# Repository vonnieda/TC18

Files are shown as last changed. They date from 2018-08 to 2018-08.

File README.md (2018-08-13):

# TC18

An IV-18 VFD tube clock by Jason von Nieda <jason@vonnieda.org>

This work is licensed under a Creative Commons Attribution-Share Alike 3.0 
United States License.
See http://creativecommons.org/licenses/by-sa/3.0/us/ for more information.

The enclosure of this clock was designed by John Pfeiffer at 
http://blog.giantpachinkomachineofdoom.com/

Parts of the circuit are based on Ladyada's Ice Tube clock at 
http://www.ladyada.net/make/icetube/
That clock is sold in kit form by Adafruit at 
http://www.adafruit.com/index.php?main_page=product_info&cPath=39&products_id=194

Some of the parts used in the schematic and board drawings are from 
the Sparkfun Eagle library at 
http://www.opencircuits.com/SFE_Footprint_Library_Eagle

# Manifest
* TC18-v3.brd: Eagle Board file.
* TC18-v3.sch: Eagle Schematic file.
* TC18.pde: Arduino sketch - this is the entire source code.
* TC18.xls: Spreadsheet containing notes, BOM and ordering info. OpenOffice and Google Docs compatible.
* FRAME 1V2.DXF: The first metal frame - rectangle with D shape cut from center.
* FRAME 2V2.DXF: The second metal frame - rectangle with rectangle cut from center.
* FRAME 3V2.DXF: The third metal frame - X shape with rectangle cut from center.
* FRAME 4V2.DXF: The fourth metal frame - this has not yet been made or proofed. Four of these will be made to go inside the perforated metal as fillers. These will be black.
* FRAME V2.DXF: Template for the metal frames. Used as the starting point for all of the above.
* PERFFORM.DXF: Used to make the wooden form that I bend the perforated aluminum around. The form is made from 2 identical pieces of 3/4" MDF glued up to be 1.5".
	
# Build Notes
I have put up a web page about this clock. If something appears to be missing from here, try checking there first:
http://www.vonnieda.org/tc18
    
# Enclosure Parts List
* 8 2.5" long 1/4" 28NF hex socket cap bolts, black oxide
* 2 "FRAME 1V2"
* 2 "FRAME 2V2"
* 2 "FRAME 3V2"
* 24 Buna-N O-Ring AS568A Dash Number 108 http://www.mcmaster.com/nav/enter.asp?partnum=9452K171&pagenum=3423
* 8 .25" length polished 6061 aluminum tube 0.375" OD x 0.065" wall x 0.245" ID bored out to .25" ID
* 8 3" length polished 6061 aluminum tube 0.375" OD x 0.065" wall x 0.245" ID with ends tapped for the bolts and to about 1" deep
* 2 end sleeves - 3003-H14 perforated aluminum 0.063" thick (0.0625" dia. holes) 0.125" stagger. Approx 1" wide formed around "PERFFORM.DXF", joined at bottom and painted gloss black

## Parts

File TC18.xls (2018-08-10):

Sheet: BOM V3
Quantity | Part | Package | Supplier | Part Number | Number in Stock | Min Quantity | Price | Extended | Notes
1 | MCU AVR 32K FLASH 32TQFP |  | Digikey | ATMEGA328P-AU-ND | 10 | 1 | $4.30
1 | IC RTC W/TCXO 16-SOIC |  | Digikey | DS3231S#-ND | 2 | 1 | $7.42
1 | MC33269D-3.3 IC REG LDO 800MA 3.3V DPAK |  | Digikey | MC33269DT-3.3GOS-ND | 1 | 1 | $0.85
1 | INDUCTOR 220UH .57A SMD SHIELDED | 0.287" L x 0.287" W x 0.180" H (7.30mm x 7.30mm x 4.55mm) | Digikey | 811-1174-1-ND | 1 | 1 | $0.96
1 | DIODE SCHOTTKY 1A 80V DO-214AA | DO-214AA, SMB | Digikey | 641-1108-1-ND | 1 | 1 | $0.42
1 | MOSFET N-CH 100V 4.3A DPAK | DPak, TO-252 (2 leads+tab), SC-63 | Digikey | IRLR110PBFCT-ND | 1 | 1 | $1.85
1 | CAP CER .10UF 100V X7R 0805 | 0805 | Digikey | HMK212B7104KG-T | 8 | 10 | $0.19
1 | CAP 22UF 63V ELECT HA SMD | 0.315" Dia x 0.244" H (8.00mm x 6.20mm) | Digikey | PCE4230CT-ND | 10 | 5 | $0.44
2 | CAP 47UF 25V ELECT HA SMD | 0.248" Dia x 0.213" H (6.30mm x 5.40mm) | Digikey | PCE3297CT-ND | 10 | 5 | $0.29
1 | CONN POWER JACK 2.1X5.5MM HI CUR |  | Digikey | CP-002AHPJCT-ND | 1 | 1 | $0.90
1 | CRYSTAL 16.00 MHZ 8.0 PF SMD |  | Digikey | 644-1135-1-ND | 0 | 1 | $1.70
2 | CAP CERAMIC 8.0PF 50V NP0 0805 | 0805 | Digikey | 311-1097-1-ND | 50 | 10 | $0.06
1 | HOLDER BATTERY COIN 12MM DIA SMD |  | Digikey | 3000K-ND | 2 | 1 | $0.57
1 | KNOB BLK GLOSS .50"DIA 6MM SHAFT |  | Digikey | 226-1152-ND | 3 | 1 | $3.80
1 | ENCODER ROTARY 11MM HORIZ 20PPR |  | Digikey | 102-1754-ND | 1 | 1 | $3.60
1 | PTC RESET 30V .200A SMD 1210 |  | Digikey | F3350CT-ND | 10 | 1 | $0.54
1 | CR1225 12mm 47mAh coin cell batteries. |  | SparkFun | PRT-00337 | 2 | 1 | $1.95
1 | Wall Adapter Power Supply - 5VDC 1A |  | SparkFun | TOL-08269 | 3 | 1 | $5.95
1 | MAX6921 |  | Maxim | MAX6921AWI+ | 1 | 1 | $9.09
1 | IV-18 Tube |  | eBay | IV-18 | 13 | 5 | $5.20
1 | TC18v3 PCB |  | Gold Phoenix | TC18v3 | 40 | 22 | $4.23

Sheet: V2 Board Errata
Lots of solder mask areas too large leaving traces uncovered. Around battery connector and mosfets. | Fixed in V3 and GoldPhoenix.dru
Forgot to wire MISO | Fixed in V3
Need more offset on the locking pins, they didn't do much. Maybe equal amount on opposite pins. | Fixed in V3 and JVN.lib
Electrolytic pads could be a little further out from center. Not critical. | Won't Fix
Change ext to be a standard Arduino header with DTR reset | Fixed in V3
Mosfet gate needs to be pulled down, currently floating if chip is not running properly | Fixed in V3
DS3231 silk not showing pin 1 | Fixed in V3
Maybe add a limiting resistor for mosfet path | Fixed in V3 with PTC
Maybe add a fuse for the whole thing (PTC) | Fixed in V3
Looks like I need to use the longer encoder | Fixed in V3
Board needs to be about 30 thous smaller in each dimension | Won't Fix
Need room for spacer around bolts | Fixed in V3
Change to smaller caps for the 25v/47uF | Fixed in V3

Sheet: Next Order
1 | 10 | MC33269DT-3.3GOS-ND | IC REG LDO 800MA 3.3V DPAK | 0 | 0.85 | 8.5
2 | 10 | 811-1174-1-ND | INDUCTOR 220UH .57A SMD SHIELDED | 0 | 0.84 | 8.4
3 | 10 | 641-1108-1-ND | DIODE SCHOTTKY 1A 80V DO-214AA | 0 | 0.318 | 3.18
4 | 4 | IRLR110PBFCT-ND | MOSFET N-CH 100V 4.3A DPAK | 0 | 1.85 | 7.4
5 | 4 | CP-002AHPJCT-ND | CONN POWER JACK 2.1X5.5MM HI CUR | 0 | 0.9 | 3.6
6 | 10 | 644-1135-1-ND | CRYSTAL 16.00 MHZ 8.0 PF SMD | 0 | 1.474 | 14.74
7 | 10 | 3000K-ND | HOLDER BATTERY COIN 12MM DIA SMD | 0 | 0.495 | 4.95
8 | 4 | 102-1754-ND | ENCODER ROTARY 11MM HORIZ 20PPR | 0 | 3.6 | 14.4

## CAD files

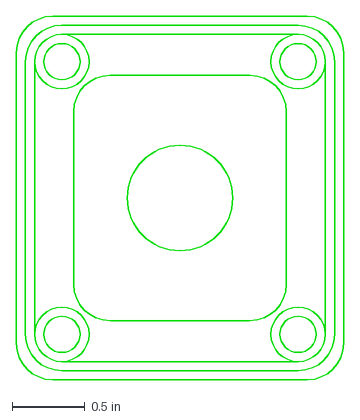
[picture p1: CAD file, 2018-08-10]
CAD/FRAME V2.DXF
2.25 x 2.50 in

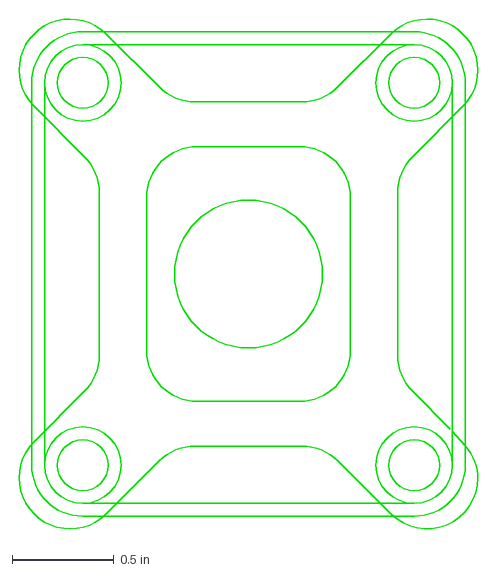
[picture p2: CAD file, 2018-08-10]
CAD/FRAME 3V2.DXF
2.28 x 2.53 in

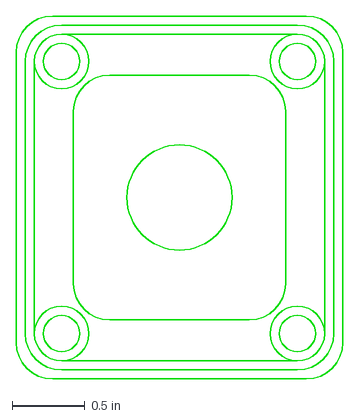
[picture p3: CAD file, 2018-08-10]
CAD/FRAME 4V2.DXF
2.25 x 2.50 in

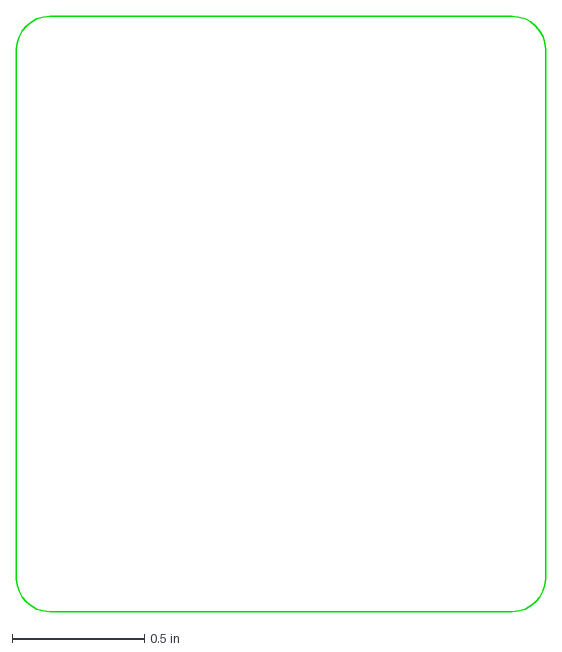
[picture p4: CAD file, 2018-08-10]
CAD/PERF FORM.DXF
2.00 x 2.25 in

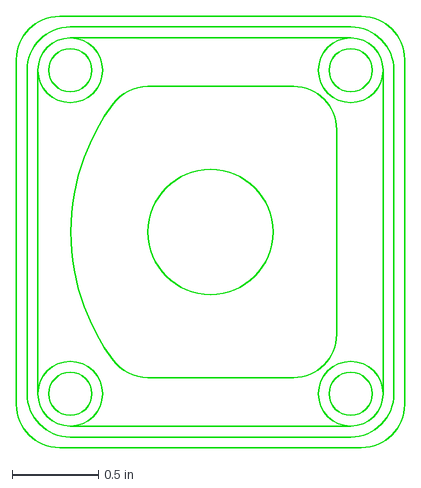
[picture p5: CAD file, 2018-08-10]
CAD/FRAME 1V2.DXF
2.25 x 2.50 in

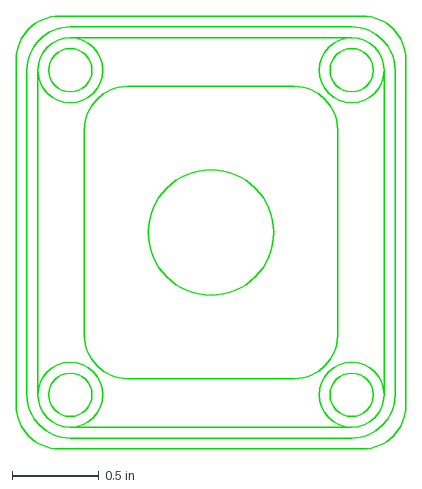
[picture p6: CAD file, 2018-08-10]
CAD/FRAME 2V2.DXF
2.25 x 2.50 in

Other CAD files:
TC18-Case.skp
TC18.skp

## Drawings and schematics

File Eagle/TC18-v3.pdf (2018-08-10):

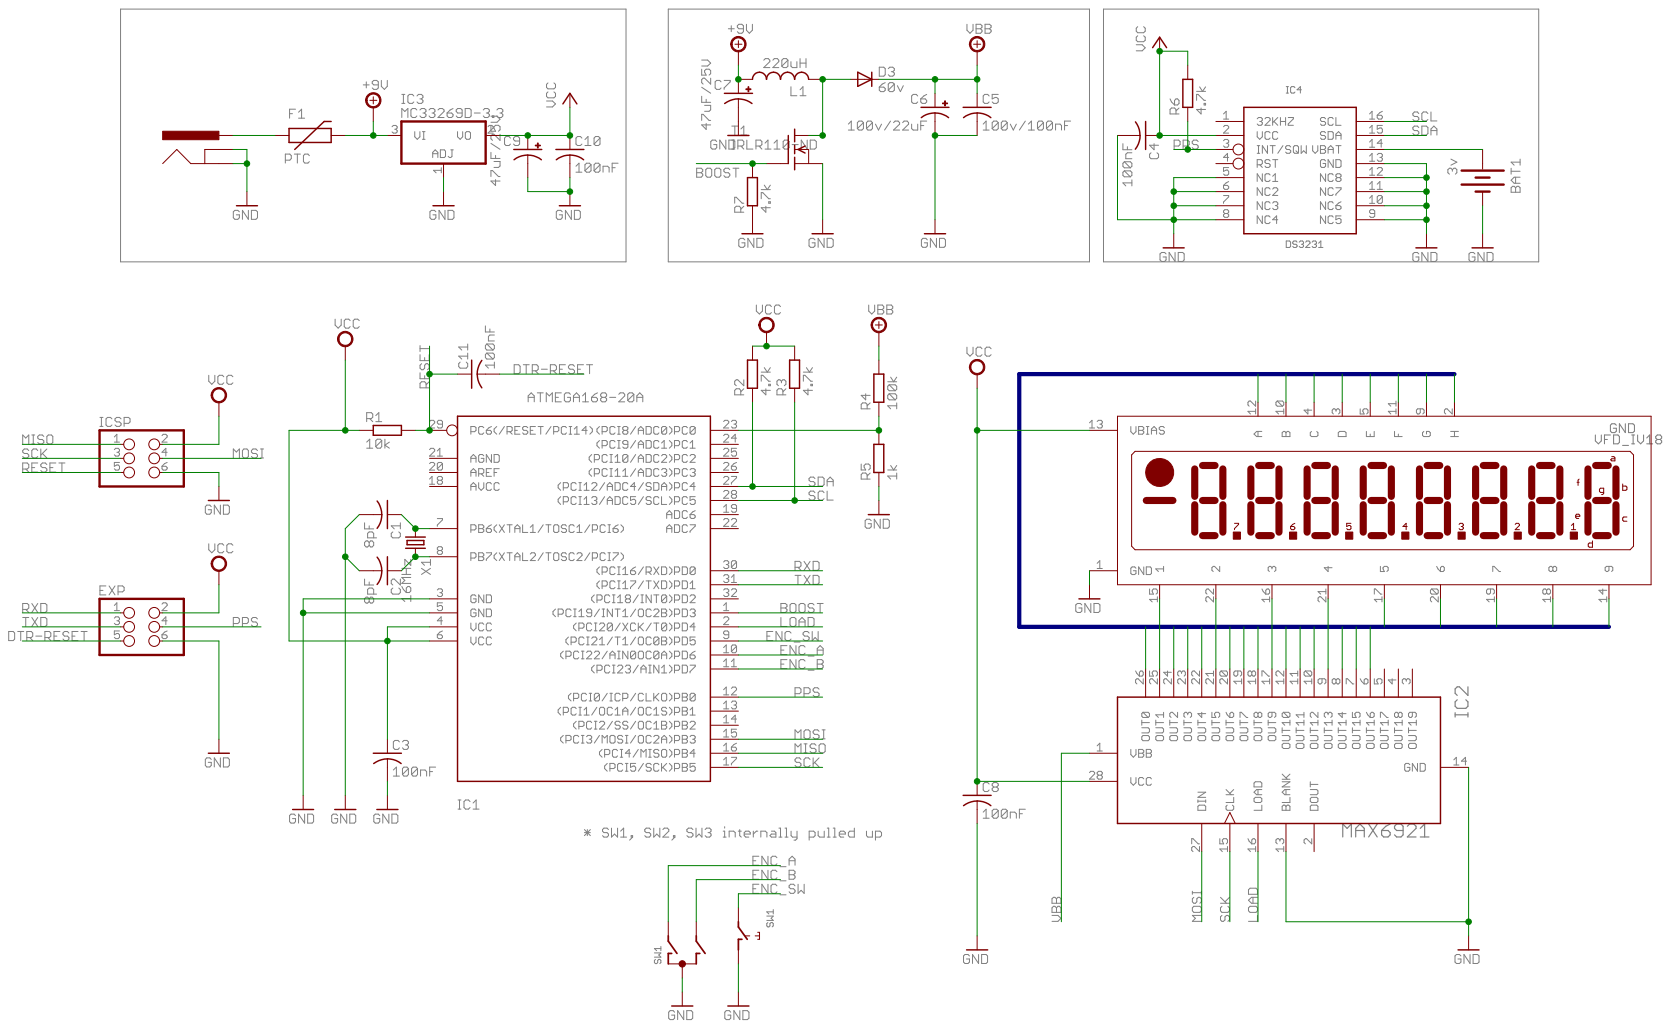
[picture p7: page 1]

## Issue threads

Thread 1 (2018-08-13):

No need to wait after Wire.requestFrom().

Koepel, 2018-08-13:
In the file "TC18/Arduino/TC18/TC18.ino", you may remove all the `while (Wire.available() < ...` after a Wire.requestFrom().
Explanation: [Common-mistakes#1](https://github.com/Koepel/How-to-use-the-Arduino-Wire-library/wiki/Common-mistakes#1)

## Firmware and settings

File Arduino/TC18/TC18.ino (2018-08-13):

/*
* TC18 by Jason von Nieda <jason@vonnieda.org>
* License: CC BY-SA
* 
* Board Configuration
*  Arduino Duemilanove or Diecimila, ATmega328P or ATmega168 @ 16MHz
*  Arduino will set the brown out detect too high on burning the bootloader
*  so it has to be changed to 1.8 manually.
*  VBB feedback       Analog 0 (PC0)
*    VBB with 100k to 1k voltage divider
*  SCK to MAX6921     Digital 13 (PB5)
*  MOSI to MAX6921    Digital 11 (PB3)
*  PPS                Digital 8 (PB0)
*  SW2 (ENC_B)        Digital 7 (PD7)
*  SW1 (ENC_A)        Digital 6 (PD6)
*  SW3 (ENC_SW)       Digital 5 (PD5)
*  LOAD               Digital 4 (PD4)
*  BOOST              Digital 3 (PD3)
*  SDA                Analog 4 (PC4)
*  SCL                Analog 5 (PC5)
*  RXD                Digital 0 (PD0)
*  TXD                Digital 1 (PD1)
*/


// Used only for testing a board after programming
//#define TESTMODE     1

#include <avr/interrupt.h>
#include <stdlib.h>
#include <stdio.h>
#include <Wire.h>
#include <EEPROM.h>

#define DS3231_ADDR   0b01101000

#define VFDLOAD_DDR   DDRD
#define VFDLOAD_PORT  PORTD
#define VFDLOAD       PORTD4

#define BOOST_DDR     DDRD
#define BOOST_PORT    PORTD
#define BOOST         PORTD3

#define PPS_DDR       DDRB
#define PPS_PIN       PINB
#define PPS           PORTB0

#define ENC_A_DDR     DDRD
#define ENC_A_PIN     PIND
#define ENC_A_PORT    PORTD
#define ENC_A         PORTD6

#define ENC_B_DDR     DDRD
#define ENC_B_PIN     PIND
#define ENC_B_PORT    PORTD
#define ENC_B         PORTD7

#define ENC_SW_DDR    DDRD
#define ENC_SW_PIN    PIND
#define ENC_SW_PORT   PORTD
#define ENC_SW        PORTD5

#define VFD_SEG_A     0b00000001
#define VFD_SEG_B     0b00000010
#define VFD_SEG_C     0b00000100
#define VFD_SEG_D     0b00001000
#define VFD_SEG_E     0b00010000
#define VFD_SEG_F     0b00100000
#define VFD_SEG_G     0b01000000
#define VFD_SEG_H     0b10000000

#define VFD_DIGIT_0   0b000000001
#define VFD_DIGIT_1   0b000000010
#define VFD_DIGIT_2   0b000000100
#define VFD_DIGIT_3   0b000001000
#define VFD_DIGIT_4   0b000010000
#define VFD_DIGIT_5   0b000100000
#define VFD_DIGIT_6   0b001000000
#define VFD_DIGIT_7   0b010000000
#define VFD_DIGIT_8   0b100000000

#define MENU_TIMEOUT  10000

static const byte vfd_font[] = {
  /* 0 - 9 */
  VFD_SEG_A | VFD_SEG_B | VFD_SEG_C | VFD_SEG_D | VFD_SEG_E | VFD_SEG_F,
  VFD_SEG_B | VFD_SEG_C,
  VFD_SEG_A | VFD_SEG_B | VFD_SEG_D | VFD_SEG_E | VFD_SEG_G,
  VFD_SEG_A | VFD_SEG_B | VFD_SEG_C | VFD_SEG_D | VFD_SEG_G,
  VFD_SEG_B | VFD_SEG_C | VFD_SEG_F | VFD_SEG_G,
  VFD_SEG_A | VFD_SEG_C | VFD_SEG_D | VFD_SEG_F | VFD_SEG_G,
  VFD_SEG_A | VFD_SEG_C | VFD_SEG_D | VFD_SEG_E | VFD_SEG_F | VFD_SEG_G,
  VFD_SEG_A | VFD_SEG_B | VFD_SEG_C,
  VFD_SEG_A | VFD_SEG_B | VFD_SEG_C | VFD_SEG_D | VFD_SEG_E | VFD_SEG_F | VFD_SEG_G,
  VFD_SEG_A | VFD_SEG_B | VFD_SEG_C | VFD_SEG_F | VFD_SEG_G,
  
  /* a - z */
  VFD_SEG_A | VFD_SEG_B | VFD_SEG_C | VFD_SEG_D | VFD_SEG_E | VFD_SEG_G,
  VFD_SEG_C | VFD_SEG_D | VFD_SEG_E | VFD_SEG_F | VFD_SEG_G,
  VFD_SEG_D | VFD_SEG_E | VFD_SEG_G,
  VFD_SEG_B | VFD_SEG_C | VFD_SEG_D | VFD_SEG_E | VFD_SEG_G,
  VFD_SEG_A | VFD_SEG_B | VFD_SEG_D | VFD_SEG_E | VFD_SEG_F | VFD_SEG_G,
  VFD_SEG_A | VFD_SEG_E | VFD_SEG_F | VFD_SEG_G,
  VFD_SEG_A | VFD_SEG_B | VFD_SEG_C | VFD_SEG_D | VFD_SEG_F | VFD_SEG_G,
  VFD_SEG_C | VFD_SEG_E | VFD_SEG_F | VFD_SEG_G,
  VFD_SEG_B | VFD_SEG_C,
  VFD_SEG_B | VFD_SEG_C | VFD_SEG_D | VFD_SEG_E,
  VFD_SEG_A | VFD_SEG_C | VFD_SEG_E | VFD_SEG_F | VFD_SEG_G,
  VFD_SEG_D | VFD_SEG_E | VFD_SEG_F,
  VFD_SEG_A | VFD_SEG_C | VFD_SEG_E | VFD_SEG_G,
  VFD_SEG_C | VFD_SEG_E | VFD_SEG_G,
  VFD_SEG_C | VFD_SEG_D | VFD_SEG_E | VFD_SEG_G,
  VFD_SEG_A | VFD_SEG_B | VFD_SEG_E | VFD_SEG_F | VFD_SEG_G,
  VFD_SEG_A | VFD_SEG_B | VFD_SEG_C | VFD_SEG_D | VFD_SEG_G | VFD_SEG_H,
  VFD_SEG_E | VFD_SEG_G,
  VFD_SEG_A | VFD_SEG_C | VFD_SEG_D | VFD_SEG_F | VFD_SEG_G,
  VFD_SEG_D | VFD_SEG_E | VFD_SEG_F | VFD_SEG_G,
  VFD_SEG_C | VFD_SEG_D | VFD_SEG_E,
  VFD_SEG_C | VFD_SEG_D | VFD_SEG_E,
  VFD_SEG_A | VFD_SEG_C | VFD_SEG_D | VFD_SEG_E,
  VFD_SEG_B | VFD_SEG_C | VFD_SEG_E | VFD_SEG_F | VFD_SEG_G,
  VFD_SEG_B | VFD_SEG_C | VFD_SEG_D | VFD_SEG_F | VFD_SEG_G,
  VFD_SEG_A | VFD_SEG_B | VFD_SEG_D | VFD_SEG_E | VFD_SEG_G,
};

static const char *month_abbrevs[] = {
  "Jan",
  "Feb",
  "Mar",
  "Apr",
  "May",
  "Jun",
  "Jul",
  "Aug",
  "Sep",
  "Oct",
  "Nov",
  "Dec",
};

volatile byte vfd_data[9];
volatile byte vfd_digit;
// Digit dwell is used to adjust the brightness of individual digits on
// the display. Used to compensate for tube manufacturing differences.
// Increasing the value of a position causes the refresh loop to dwell on
// that digit for additional cycles causing it's brightness to increase.
// Use sparingly. This slows the refresh of the entire display.
// No need to change here, there is a menu option and it is saved
// to EEPROM.
volatile byte vfd_digit_dwell[] = {
  0, 0, 0, 0, 0, 0, 0, 0, 0
};
volatile byte vfd_digit_dwell_count;
volatile unsigned long spi_buffer;
volatile byte spi_buffer_count;

// Default boost voltage used during startup, this is quickly replaced by the
// config data
float voltage_target = 30.00;
// The allowable voltage +/- drift before the ADC interrupt makes adjustements
static const float voltage_drift = 3.00;
// The current voltage as measured by the ADC
float voltage;
// The number of times the voltage has been sampled. This is used to limit
// the frequency of updates to the boost PWM.
byte voltage_sample;

volatile char encoder_debounce = -1;
volatile char encoder_pos;
volatile char encoder_pressed;

volatile byte hour, minute, second, year, month, date;
volatile unsigned int millisecond;
volatile float temperature;

// Used in many main loop functions to format text for display
char display_buf[20];

// Configurable options, pulled from EEPROM at startup and stored
// when changed.
char display_mode;
char brightness;
char bank_mode;
char glitch_mode;

#define GLITCHES 3
static int glitch_digit[GLITCHES];
static int glitch_segment[GLITCHES];
static int glitch_count[GLITCHES];
static bool glitch_on[GLITCHES];

void setup() {
  Serial.begin(19200);
  
  BOOST_DDR |= _BV(BOOST);

  // Timer 2 is used to create the waveform for the boost controller
  // Timer 2 Waveform Generation Mode 3 Fast PWM
  // Compare Output Mode Clear OC2B on Compare Match, set OC2B at BOTTOM
  TCCR2A = _BV(WGM21) | _BV(WGM20) | _BV(COM2B1);
  // Clock Select No Prescaling
  TCCR2B = _BV(CS20);
  // Initial value for boost timer
  OCR2B = 230;
  
  // Timer 1 is used to refresh the VFD display
  // Set defaults in case Arduino screws them up
  TCCR1A = 0;
  // Clock Select No Prescaling
  TCCR1B = _BV(CS10);
  // Interrupt Enable
  TIMSK1 = _BV(TOIE1);
  
  // Internal 1.1V Voltage Reference, Single Ended Input on ADC0
  ADMUX = _BV(REFS1) | _BV(REFS0);
  // ADC Enable, ADC Auto Trigger Enable, ADC Interrupt Enable
  // ADC Prescaler 128
  ADCSRA |= _BV(ADEN) | _BV(ADATE) | _BV(ADIE) 
    | _BV(ADPS2) | _BV(ADPS1) | _BV(ADPS0);
  // ADC Start Conversion (starts free running mode)
  ADCSRA |= _BV(ADSC);
  
  // Enable SS, MOSI and SCK as outputs, required by SPI
  DDRB |= _BV(PORTB2) | _BV(PORTB3) | _BV(PORTB5);
  // SPI Enable, Master Mode, Interrupt Enable, FOSC/16
  SPCR = _BV(SPE) | _BV(MSTR) | _BV(SPR0) | _BV(SPIE);
 
  VFDLOAD_DDR |= _BV(VFDLOAD);
  
  // Enable Pin Change Interrupt 0 PCINT0 (PB0) [PPS]
  PCICR |= _BV(PCIE0);
  PCMSK0 |= _BV(PCINT0);
  
  // Set ENC_A, ENC_B and ENC_SW pins to input
  ENC_A_DDR &= ~(_BV(ENC_A));
  ENC_B_DDR &= ~(_BV(ENC_B));
  ENC_SW_DDR &= ~(_BV(ENC_SW));
  
  // Turn on internal pullups for ENC_A, ENC_B, ENC_SW
  ENC_A_PORT |= _BV(ENC_A);
  ENC_B_PORT |= _BV(ENC_B);
  ENC_SW_PORT |= _BV(ENC_SW);
  
  // Enable Pin Change Interrupt 2 for PCINT22 (PD6) [ENC_A], PCINT23 (PD7) [ENC_B], PCINT21 (PD5) [ENC_SW]
  PCMSK2 |= _BV(PCINT21);
  PCMSK2 |= _BV(PCINT22);
  PCMSK2 |= _BV(PCINT23);
  PCICR |= _BV(PCIE2);
  
  ds3231_setup();
  
  load_config();
}

void ds3231_setup() {
  Wire.begin();
  // set the control register
  ds3231_set_register(0x0e, 0b00000000);
}

byte dec_to_bcd(int dec) {
  return ((dec % 10) | ((dec / 10) << 4));
}

int bcd_to_dec(byte bcd) {
  return (((bcd >> 4) * 10) + (bcd & 0x0f));
}

void ds3231_set_register(byte address, byte value) {
  Wire.beginTransmission(DS3231_ADDR);
  Wire.write(address);
  Wire.write(value);
  Wire.endTransmission();
}

byte ds3231_get_register(byte address) {
  Wire.beginTransmission(DS3231_ADDR);
  Wire.write(address);
  Wire.endTransmission();
  Wire.requestFrom(DS3231_ADDR, 1);
  while (Wire.available() < 1);
  return Wire.read();
}

void ds3231_set_time(byte hour, byte minute, byte second) {
  Wire.beginTransmission(DS3231_ADDR);
  Wire.write(0x00);
  Wire.write(dec_to_bcd(second));
  Wire.write(dec_to_bcd(minute));
  Wire.write(dec_to_bcd(hour));
  Wire.endTransmission();
}

void ds3231_get_time(byte *hour, byte *minute, byte *second) {
  Wire.beginTransmission(DS3231_ADDR);
  Wire.write(0x00);
  Wire.endTransmission();
  Wire.requestFrom(DS3231_ADDR, 3);
  while (Wire.available() < 3);
  byte s = Wire.read();
  byte m = Wire.read();
  byte h = Wire.read();
  *second = bcd_to_dec(s);
  *minute = bcd_to_dec(m);
  *hour = bcd_to_dec(h);
}

void ds3231_set_date(byte year, byte month, byte date) {
  Wire.beginTransmission(DS3231_ADDR);
  Wire.write(0x04);
  Wire.write(dec_to_bcd(date));
  Wire.write(dec_to_bcd(month));
  Wire.write(dec_to_bcd(year));
  Wire.endTransmission();
}

void ds3231_get_date(byte *year, byte *month, byte *date) {
  Wire.beginTransmission(DS3231_ADDR);
  Wire.write(0x04);
  Wire.endTransmission();
  Wire.requestFrom(DS3231_ADDR, 3);
  while (Wire.available() < 3);
  byte d = Wire.read();
  byte m = Wire.read();
  byte y = Wire.read();
  *date = bcd_to_dec(d);
  *month = bcd_to_dec(m & 0b00011111);
  *year = bcd_to_dec(y);
}

float ds3231_get_temp() {
  byte msb = ds3231_get_register(0x11);
  byte lsb = ds3231_get_register(0x12);
  float c = msb + ((lsb >> 6) * 0.25f);
  return c;
}

/*
  Load the given VFD data into the SPI buffer and start the transfer.
  This sends the first byte of the data. The rest is sent from the
  SPI interrupt.
*/
static inline void vfd_send(unsigned long d) {
  spi_buffer = d << 8;
  spi_buffer_count = 3;
  
  SPDR = (spi_buffer >> 24);
  spi_buffer <<= 8;
  spi_buffer_count--;
}

/*
  Refresh the VFD by showing the next digit
*/
static inline void vfd_refresh() {
  if (vfd_digit_dwell_count--) {
    return;
  }
  vfd_digit_dwell_count = vfd_digit_dwell[8 - vfd_digit];
  uint32_t d = vfd_data[8 - vfd_digit];

  // glitch mode
  if (glitch_mode) {
    for (int i = 0; i < GLITCHES; i++) {
      if (vfd_digit == glitch_digit[i]) {
        glitch_count[i]--;
        if (glitch_count[i] == 0 || !(d & (1 << glitch_segment[i]))) {
          // chance to pick a new digit
          if (rand() % 1000 < 1) {
            glitch_digit[i] = rand() % 9;
          }
          // chance to pick a new segment
          if (rand() % 1000 < 10) {
            glitch_segment[i] = rand() % 8;
          }
          glitch_on[i] = !glitch_on[i];
          if (glitch_on[i]) {
            glitch_count[i] = 1 + (rand() % 1000);
          }
          else {
            glitch_count[i] = 1 + (rand() % 15);
          }
        }
        if (!glitch_on[i]) {
          d &= ~(_BV(glitch_segment[i]));
        }
      }
    }
  }
    
  d <<= 9;
  d |= (1 << vfd_digit);
  vfd_send(d);
  vfd_digit++;
  if (vfd_digit > 8) {
    vfd_digit = 0;
  }
}
  
/*
  Map the given char to the correct VFD segment byte
  using the font table and some internals.
   a
 f   b  
   g  
 e   c   
   d
       h   
*/
byte vfd_map_char(char c) {
  if (c >= 'a' && c <= 'z') {
    return vfd_font[c - 'a' + 10]; 
  }
  else if (c >= 'A' && c <= 'Z') {
    return vfd_font[c - 'A' + 10];
  }
  else if (c >= '0' && c <= '9') {
    return vfd_font[c - '0']; 
  }
  else if (c == ' ') {
    return 0; 
  }
  else if (c == '-') {
    return VFD_SEG_G;
  }
  else if (c == '.') {
    return VFD_SEG_H;
  }
  else if (c == '!') {
    return VFD_SEG_B | VFD_SEG_C | VFD_SEG_H;
  }
  else if (c == '?') {
    return VFD_SEG_A | VFD_SEG_B | VFD_SEG_E | VFD_SEG_G | VFD_SEG_H;
  }
  else if (c == ',') {
    return VFD_SEG_C;
  }
  else if (c == -1) {
    return VFD_SEG_G | VFD_SEG_H;
  }
  else {
    return 0; 
  }
}

/*
  Print the given string to the VFD
*/
void vfd_set_string(char *s, int offset) {
  int slen = strlen(s);
  
  for (int i = offset; i < offset + 8; i++) {
    if (i < 0 || i > slen - 1) {
      vfd_data[i - offset + 1] = 0;
    }
    else {
      vfd_data[i - offset + 1] = vfd_map_char(s[i]);
    }
  }
}

void vfd_scroll_string(char *s, int del) {
  int slen = strlen(s);
  for (int i = -7; i < slen; i++) {
    vfd_set_string(s, i);
    delay(del);
  }
}

int serial_readline(char *s, int length) {
  int ch;
  do {
    ch = Serial.read();
    *s++ = ch;
  } while (ch != '\n' && ch != '\r' && Serial.available() > 0);
  *s = NULL;
  return 0;
}

/*
  Handles the ADC conversion complete interrupt. ADC is used to
  measure the output of the voltage boost circuit and adjusts it
  to stay near the target voltage by adjusting the PWM width
  going to the boost MOSFET.
*/
ISR(ADC_vect) {
  byte low = ADCL;
  byte high = ADCH;
  if (voltage_sample++ > 20) {
    voltage_sample = 0;
    int adc = (high << 8) | low;
    voltage = 1.066f / (0x3ff - 1) * adc * 112.344;
    // We don't let the boost generator go below 10 or above 230
    // Those equate to roughly VCC and 60v so allowing it to
    // go too high can start blowing up components.
    if (voltage > voltage_target + voltage_drift && OCR2B > 10) {
      OCR2B--;
    }
    else if (voltage < voltage_target - voltage_drift && OCR2B < 230) {
      OCR2B++;
    }
  }
}

/**
 * Based on the algorithm described in:
 * http://www.buxtronix.net/2011/10/rotary-encoders-done-properly.html
 *
 * Implements a simple state machine that allows only valid transitions
 * from state to state. Invalid transitions are ignored, making
 * debouncing unneeded.
 *
 * The encoder, being a quadrature encoder has 4 states per detent.
 * Since we are only interested in the "full step" state, which happens
 * once per detent, we only increment our encoder_position during those
 * transitions. We still keep track of the state and the other
 * transitions, though, to keep the state machine proceeding.
 *
 * The states are:
 * A B
 * ---
 * 0 0
 * 0 1
 * 1 1
 * 1 0
 *
 * Since the encoder can turn CW or CCW, the valid next states for
 * any current state are the one before and the one after, including
 * wrapping around front to back. In other words, if the encoder is
 * currently at 00, the next valid states are 01 (CW) or 10 (CCW). Any
 * other transition is invalid and should be ignored.
 *
 * Note that this can be done with clever use of lookup tables, but
 * I feel the verbose version below is easier to understand.
 *
 * The code below is intended to be called any time there is an
 * interrupt on either of the A or B pins. The encoder_position
 * variable is updated when appropriate and then an event is
 * queued when the position changes.
 */
static int8_t encoder_read() {
  static uint8_t state = 0;
  uint8_t a = (ENC_A_PIN & _BV(ENC_A)) == 0;
  uint8_t b = (ENC_B_PIN & _BV(ENC_B)) == 0;
  uint8_t new_state = (a << 1) | b;
  switch (state) {
    case 0b00:
      switch (new_state) {
        case 0b01:
          state = new_state;
          break;
        case 0b10:
          state = new_state;
          return 1;
      }
      break;
    case 0b01:
      switch (new_state) {
        case 0b11:
          state = new_state;
          break;
        case 0b00:
          state = new_state;
          break;
      }
      break;
    case 0b11:
      switch (new_state) {
        case 0b10:
          state = new_state;
          break;
        case 0b01:
          state = new_state;
          break;
      }
      break;
    case 0b10:
      switch (new_state) {
        case 0b00:
          state = new_state;
          return -1;
          break;
        case 0b11:
          state = new_state;
          break;
      }
      break;
  }
  return 0;
}

/*
  Timer fires approx. every 1ms and handles refreshing the VFD,
  debouncing inputs and updating the milliscond time register.
*/
ISR(TIMER1_OVF_vect) {
  // fire approx every 1ms
  TCNT1 = 0xffff - 16000;
  
  millisecond++;
  
  if (encoder_debounce >= 0) {
    encoder_debounce--;
  }
  
  if (encoder_debounce == 0) {
    int encoder_sw = (ENC_SW_PIN & _BV(ENC_SW));
    
    if (!encoder_sw) {
      encoder_pressed++;
    }
  }

  vfd_refresh();
}

/*
  Picks up interrupts from any of the encoder pins changing and
  starts the debounce procedure. 
*/
ISR(PCINT2_vect) {
  encoder_debounce = 10;
  encoder_pos -= encoder_read();  
}

/*
  Handles interrupts from the PPS (pulse per second) interrupt
  updating all the time registers
*/
ISR(PCINT0_vect) {
  if (PPS_PIN & _BV(PPS)) {
    // we have to enable interrupts because the Wire library uses them
    sei();
    ds3231_get_time((byte *) &hour, (byte *) &minute, (byte *) &second);
    ds3231_get_date((byte *) &year, (byte *) &month, (byte *) &date);
    temperature = ds3231_get_temp();
    millisecond = 0;
  }
}

/*
  Handles the completion of a SPI transfer and either latches
  the data or starts the transfer of the next byte
*/
ISR(SPI_STC_vect) {
  if (spi_buffer_count) {
    SPDR = (spi_buffer >> 24);
    spi_buffer <<= 8;
    spi_buffer_count--;
  }
  else {
    // latch data
    VFDLOAD_PORT |= _BV(VFDLOAD);
    VFDLOAD_PORT &= ~_BV(VFDLOAD);
  }
}

/*
  Wait the given number of milliseconds (ms) for any input from the encoder.
  If there is input the enc_moved and enc_pressed references are filled in
  and the function returns true. If no input is detected before the
  timer expires the function returns false.
  This function clears the global input counters in either case.
*/
boolean wait_for_input(int ms, char *enc_pos, boolean *enc_pressed) {
  unsigned long m = millis() + ms;
  while (!encoder_pressed && !encoder_pos && (millis() < m));
  *enc_pos = encoder_pos;
  *enc_pressed = encoder_pressed;
  encoder_pressed = 0;
  encoder_pos = 0;
  return *enc_pressed || *enc_pos;
}

void load_config() {
  byte b;

  b = EEPROM.read(0);
  if (b == 255) {
    b = 0;
  }
  display_mode = b;
  
  b = EEPROM.read(1);
  if (b == 255) {
    b = 2;
  }
  brightness = b;
  voltage_target = 20.0 + ((brightness + 1) * 3.75);
  
  b = EEPROM.read(2);
  if (b == 255) {
    b = 1;
  }
  bank_mode = b;
  
  for (byte i = 0; i < 9; i++) {
    b = EEPROM.read(3 + i);
    if (b == 255) {
      b = 0;
    }
    vfd_digit_dwell[i] = b;
  }
  
  b = EEPROM.read(20);
  if (b == 255) {
    b = 0;
  }
  glitch_mode = b;
}

void save_config() {
  EEPROM.write(0, display_mode);
  EEPROM.write(1, brightness);
  EEPROM.write(2, bank_mode);
  for (byte i = 0; i < 9; i++) {
    EEPROM.write(3 + i, vfd_digit_dwell[i]);
  }
  EEPROM.write(20, glitch_mode);
}
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
void loop() {
  #ifdef TESTMODE
  test_loop();
  return;
  #endif
  char enc_moved = 0;
  boolean enc_pressed = 0;
  for (;;) {
    // This effectively defines the refresh rate for the clock data. We wait for input
    // for 10 ms and then refresh the clock.
    if (wait_for_input(10, &enc_moved, &enc_pressed)) {
      main_menu();
    }
    switch (display_mode) {
      case 0: {
        sprintf(display_buf, "%02d:%02d:%02d", hour, minute, second);
        vfd_data[0] = 0;
        break;
      }
      case 1: {
        sprintf(display_buf, "%02d%02d  %02d", hour, minute, date);
        vfd_data[0] = (second % 2 ? VFD_SEG_H : 0);
        break;
      }
      case 2: {
        sprintf(display_buf, "%02d%02d %dF", hour, minute, (int) c_to_f(temperature));
        vfd_data[0] = (second % 2 ? VFD_SEG_H : 0);
        break;
      }
      case 3: {
        sprintf(display_buf, "%s %02d", month_abbrevs[month - 1], date);
        vfd_data[0] = 0;
        break;
      }
      case 4: {
        uint64_t t = (24L * 60L * 60L * 1000L) - ((hour * 60L * 60L * 1000L) + (minute * 60L * 1000L) + (second * 1000L) + millisecond);
        sprintf(display_buf, "%08lu", t);
        vfd_data[0] = 0;
        break;
      }
      case 5: {
        sprintf(display_buf, "%02d%02d  %02d", hour, minute, (int) voltage);
        vfd_data[0] = (second % 2 ? VFD_SEG_H : 0);
        break;
      }
    }
    if (bank_mode) {
      if (second % 12 < 4) {
          sprintf(display_buf, "%02d-%02d-%02d", month, date, year);
          vfd_data[0] = 0;
      }
      else if (second % 12 < 8) {
          sprintf(display_buf, "%dF %dC", (int) c_to_f(temperature), (int) temperature);
          vfd_data[0] = 0;
      }
    }
    vfd_set_string(display_buf, 0);
  }
}

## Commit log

2018-08-10 Did I really never source control this?
    [FRAME 1V2.DXF, FRAME 2V2.DXF, FRAME 3V2.DXF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]
2018-08-10 Added state machine based encoder handling. Increased debounce on encoder switch.
2018-08-10 v4 was never actually made - the files were no different than v3 in a diff. The EPS files are what was used to panelized the case parts.
    [TC18-v4.brd, TC18-v4.sch]
